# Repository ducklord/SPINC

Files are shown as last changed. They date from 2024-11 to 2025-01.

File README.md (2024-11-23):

# SPINC - DIY Automatic Battery Charger

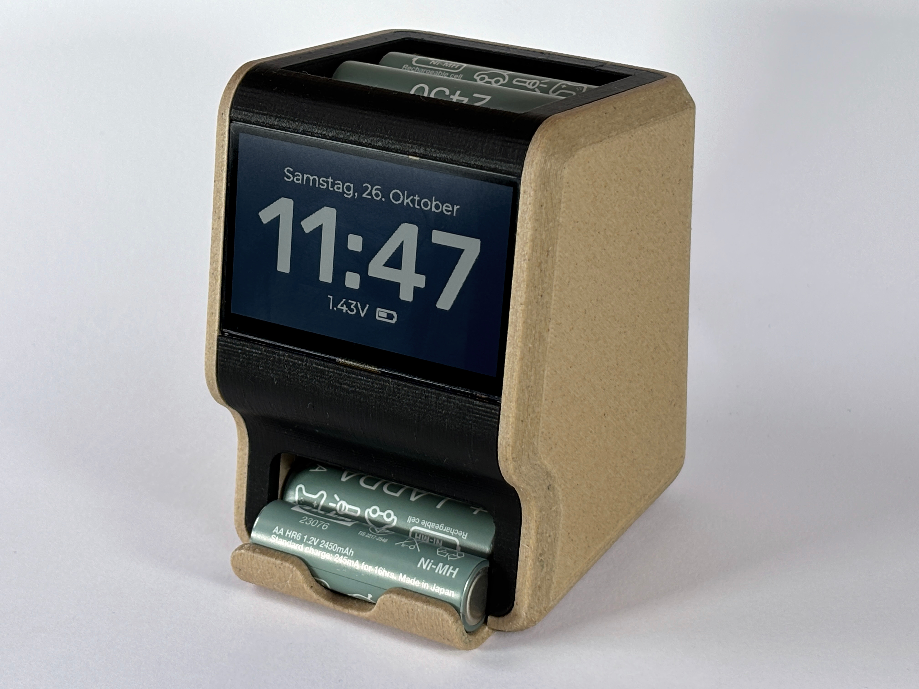
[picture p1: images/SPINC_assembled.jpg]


## Overview

SPINC is an Open-Source NiMH charging station that can automatically load and eject AA battery cells. Simply drop batteries into the top of the device, regardless of their polarity. The internal mechanism picks up one cell at a time and fast-charges them sequentially. Up to 7 fully charged batteries can be conveniently stored inside the device for easy access. In addition, SPINC doubles as a desk clock, displaying the date and time on its high-resolution LCD.

<div align="center">
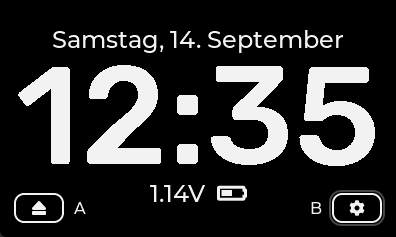
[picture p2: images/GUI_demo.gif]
  
</div>

### Features
* Fast-charges AA NiMH cells at up to 1A
* Automatic cell loading and ejection
* Electronic polarity-correction
* Voltage, temperature and charge time monitoring
* 240x400px monochrome LCD
* Date and time display using LVGL interface
* Compact and fully 3D-printed

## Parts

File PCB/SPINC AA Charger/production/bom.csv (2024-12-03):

Designator | Footprint | Quantity | Value | LCSC Part #
C1, C3 | 0603 | 2 | 4.7uF | C15849
C10, C13, C14, C16, C18, C19, C21, C22, C24, C26, C27, C28 | 0603 | 12 | 100nF
C11, C12 | 0603 | 2 | 15pF | C107037
C15, C17, C2, C20, C4, C6, C8, C9 | 0603 | 8 | 1uF | C15849
C25, C5 | 0603 | 2 | 2.2uF
C29 | 0603 | 1 | 1uF
C30 | 0603 | 1 | 10uF | C15849
C7 | 0603 | 1 | 2.2uF | C15849
D1, D5 | 0603 | 2 | LED | C965807
D2, D4 | D_SMA | 2 | MBRA340
D3 | TSOT-23 | 1 | MMBD4148
F1 | 1206 | 1 | 1A
J1 | USB_C_Receptacle_HRO_TYPE-C-31-M-12 | 1 | USB_C_Receptacle_USB2.0 | C2982555
J2 | PinHeader_1x03_P2.54mm_Vertical | 1 | Conn_01x03_Pin
J3 | 68711014022 | 1 | Conn_01x10_Socket | C2919540
J4, J5 | BatteryHolder_Keystone_590 | 2 | Conn_01x01_Pin | C3029553
L1 | L_Bourns_SRP7050TA_7.3x6.6mm | 1 | SRP7050TA-470M
Q1, Q3 | SOT-23 | 2 | DMG2301L | C102619
Q2 | SO-8_3.9x4.9mm_P1.27mm | 1 | DMHC3025LSD | C156387
Q4 | SOT-23 | 1 | DMG2301L
Q5 | SOT-23 | 1 | SI2305CDS
R10, R14 | 0603 | 2 | 2k2 | C114662
R15, R16, R19, R24, R25, R26, R27, R31, R36, R9 | 0603 | 10 | 10k
R18, R23 | 0603 | 2 | 4k7
R2 | 0603 | 1 | 1k
R20 | 0603 | 1 | 0
R21, R22, R28, R29 | 0603 | 4 | 47k
R3, R4 | 0603 | 2 | 5.1k | C114626
R30 | 0603 | 1 | 100
R32 | 0603 | 1 | 22k
R33 | 0603 | 1 | 100k
R34 | 2512 | 1 | 0R124
R35 | 0603 | 1 | 10
R37 | 0603 | 1 | 330
R5 | 0603 | 1 | 100k | C114626
R6 | 0603 | 1 | 57.6k | C114626
R7, R8 | 0603 | 2 | 27
SW1, SW3 | Panasonic_EVQPUM_EVQPUD | 2 | SW_Push | C388642
SW2 | SW_SPST_EVQP2 | 1 | SW_Push | C2915174
TH1, TH2 | 0603 | 2 | Thermistor_NTC | C13564
U1 | WSON-8-1EP_2x2mm_P0.5mm_EP0.9x1.6mm | 1 | LM27761
U2 | SOT-666 | 1 | USBLC6-2P6 | C2827693
U3 | WSON-8-1EP_6x5mm_P1.27mm_EP3.4x4.3mm | 1 | W25Q64JVZPIQ | C2940197
U4 | SOT-23-5 | 1 | AP2112K-3.3 | C51118
U5 | QFN-56-1EP_7x7mm_P0.4mm_EP3.2x3.2mm | 1 | RP2040 | C2040
U7 | VISHAY_VCNL4040_4X2X1.1 | 1 | VCNL4040M3OE | C142526
U8 | TSSOP-16_4.4x5mm_P0.65mm | 1 | DS2712
Y1 | Crystal_SMD_Abracon_ABM8G-4Pin_3.2x2.5mm | 1 | ABM8-272-T3 | C20625731

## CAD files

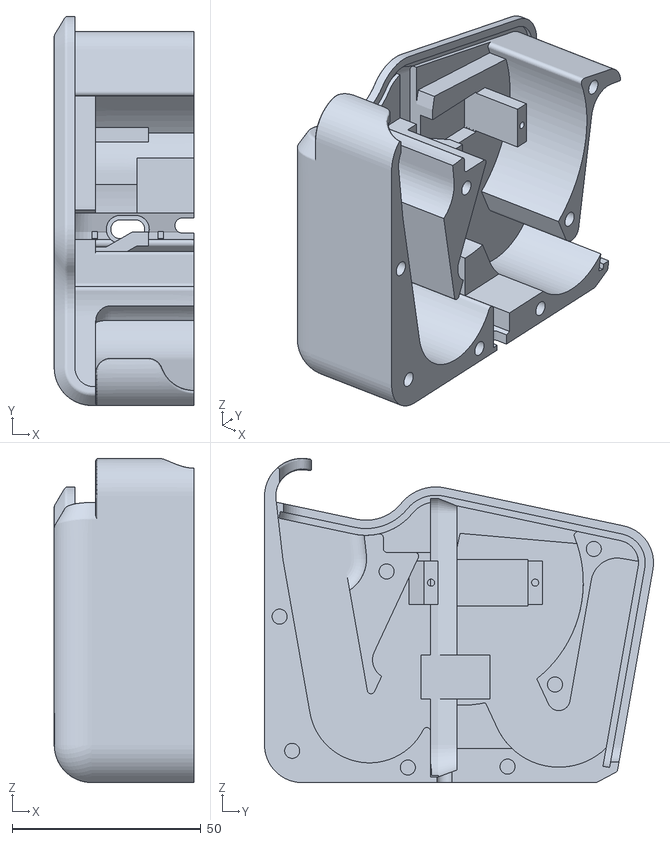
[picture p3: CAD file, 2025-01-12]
CAD/Shell L.stl
37.0 x 103.1 x 85.9

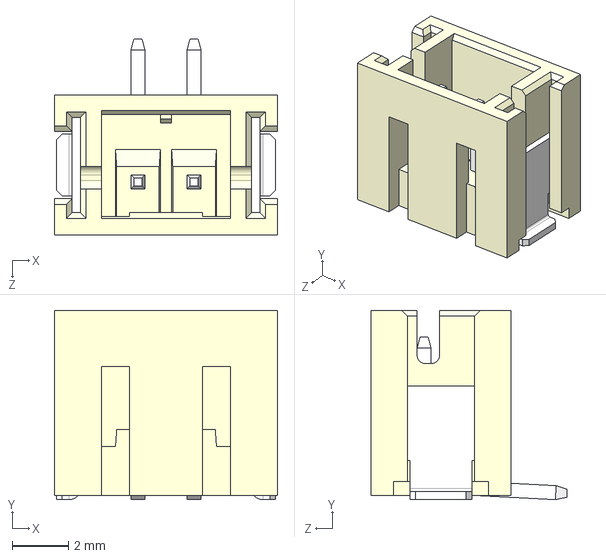
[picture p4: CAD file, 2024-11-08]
PCB/SPINC AA Charger/project_libraries/3D-models/B2B-PH-SM4-TB.STEP
7.95 x 6.75 x 7.00 mm

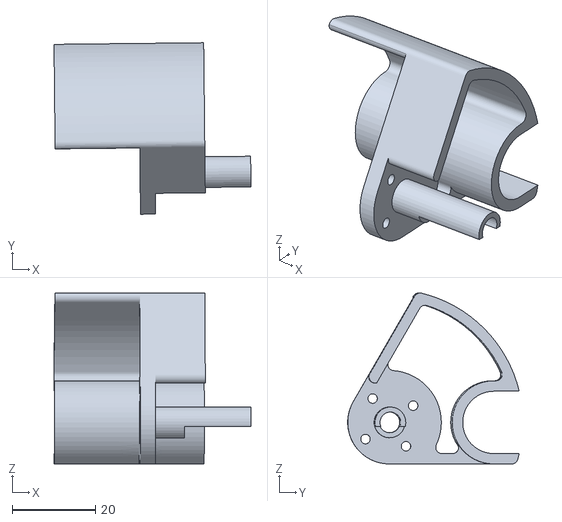
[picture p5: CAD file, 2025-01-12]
CAD/Arm.stl
47.4 x 41.3 x 41.1

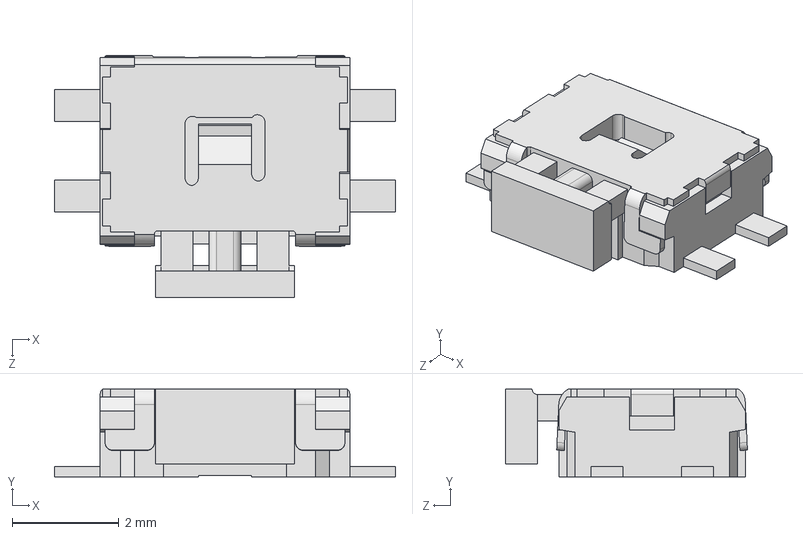
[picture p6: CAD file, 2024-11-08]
PCB/SPINC AA Charger/project_libraries/3D-models/EVQPU-JA-02K.STEP
6.40 x 1.65 x 4.54 mm

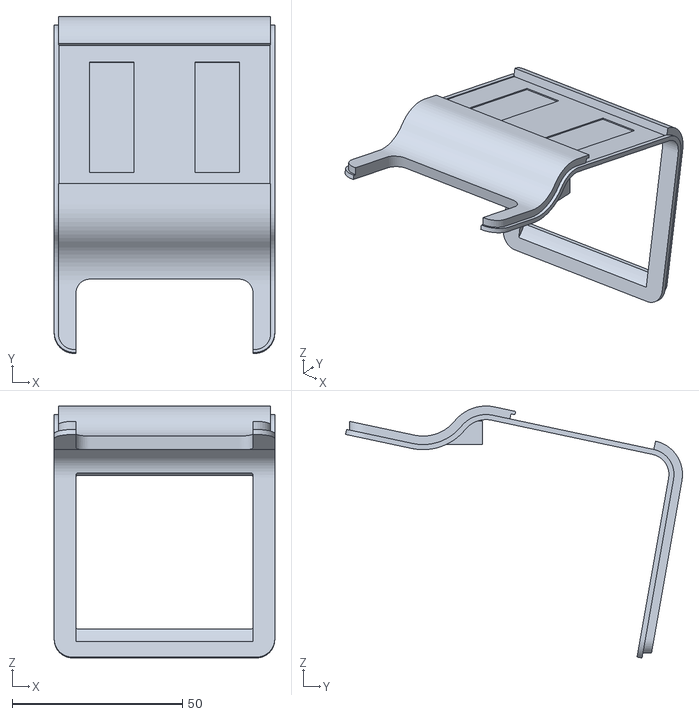
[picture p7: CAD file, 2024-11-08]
CAD/Frontpanel.stl
64.8 x 99.0 x 74.0

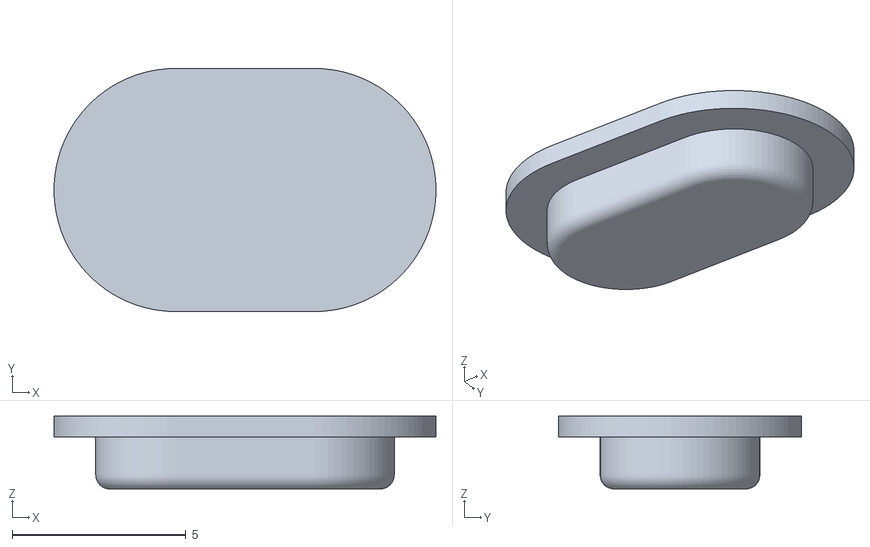
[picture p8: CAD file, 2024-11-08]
CAD/Button.stl
11.0 x 7.00 x 2.10

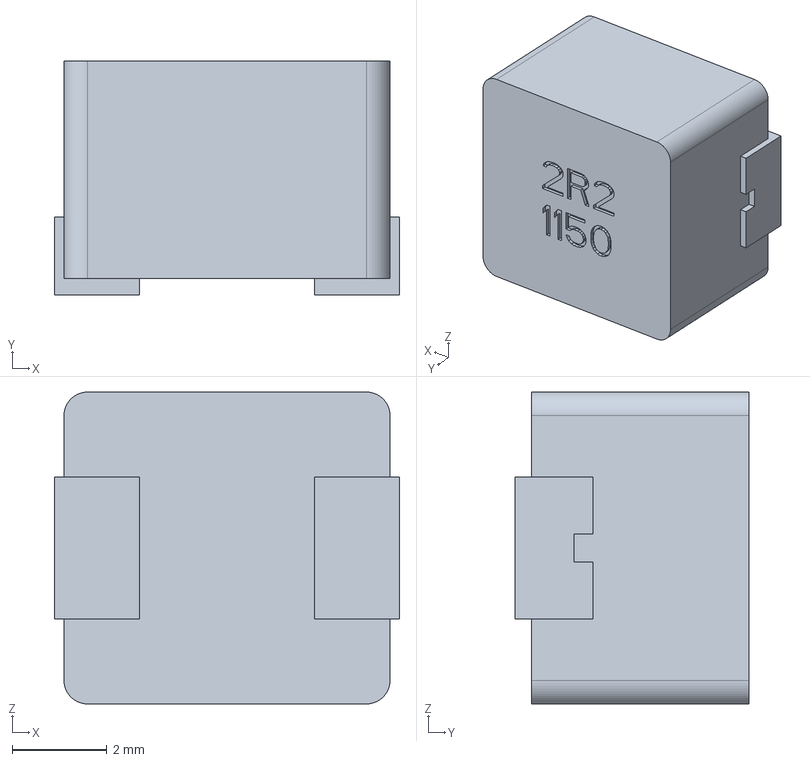
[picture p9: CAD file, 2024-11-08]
PCB/SPINC AA Charger/project_libraries/3D-models/SRP7050TA.stp
7.30 x 4.95 x 6.60 mm

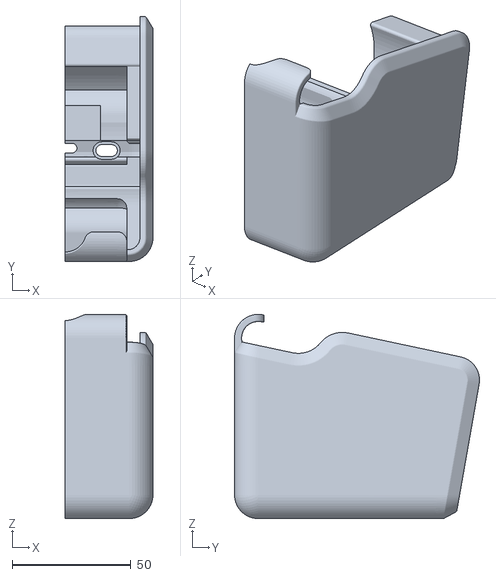
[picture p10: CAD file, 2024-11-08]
CAD/Shell R.stl
37.0 x 103.1 x 85.9

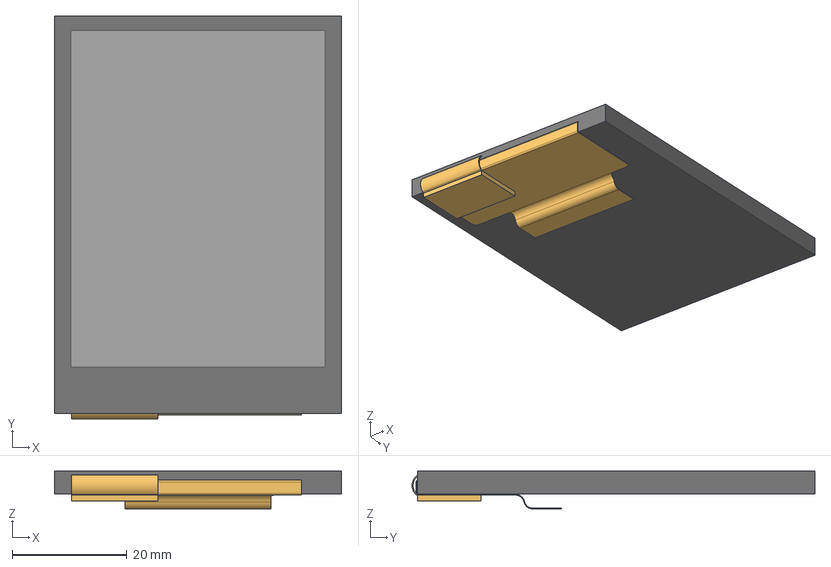
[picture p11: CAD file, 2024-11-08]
PCB/SPINC AA Charger/project_libraries/3D-models/280QV10 v5.step
50.0 x 70.2 x 6.60 mm

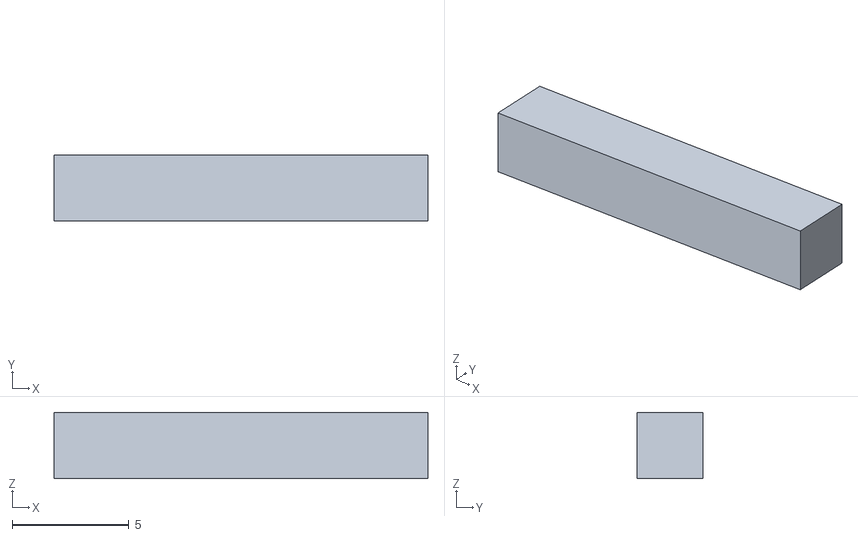
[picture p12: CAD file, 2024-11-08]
CAD/Connector Pin.stl
16.0 x 2.83 x 2.83

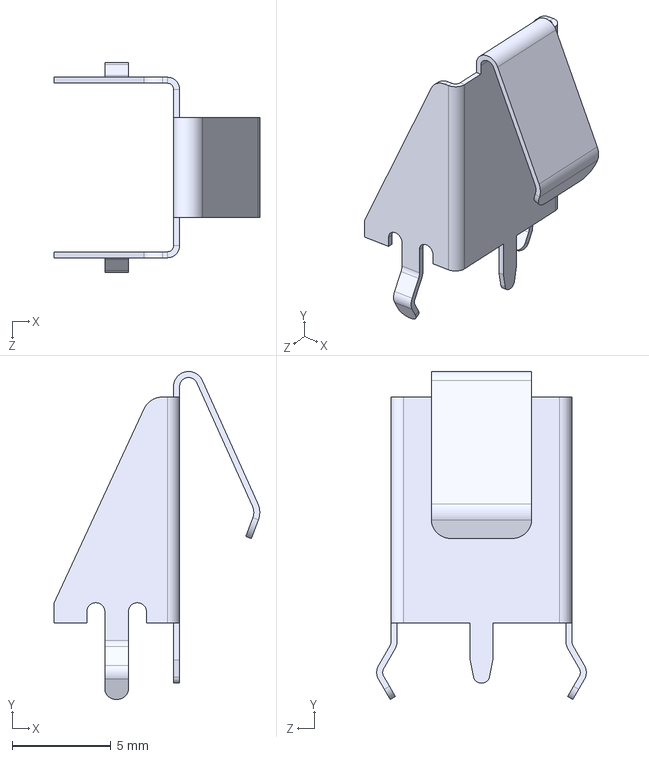
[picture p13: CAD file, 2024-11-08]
PCB/SPINC AA Charger/project_libraries/3D-models/keystone-PN590.STEP
10.4 x 16.6 x 10.6 mm

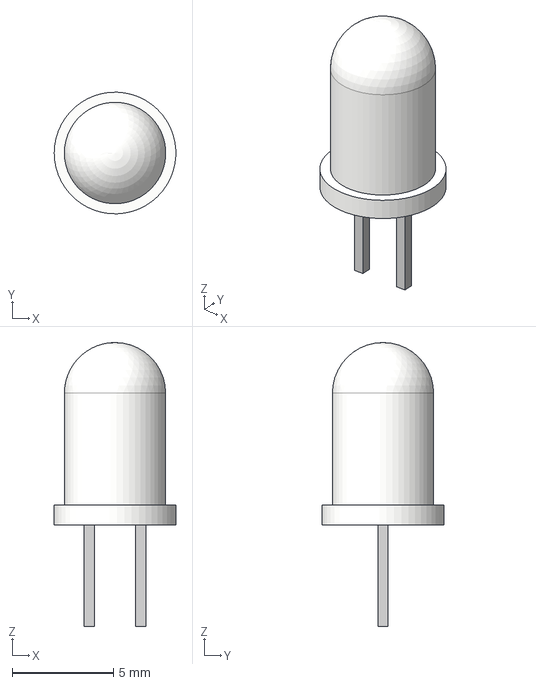
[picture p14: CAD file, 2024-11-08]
PCB/SPINC AA Charger/project_libraries/3D-models/Side Mount LED v1.step
5.99 x 6.00 x 14.0 mm

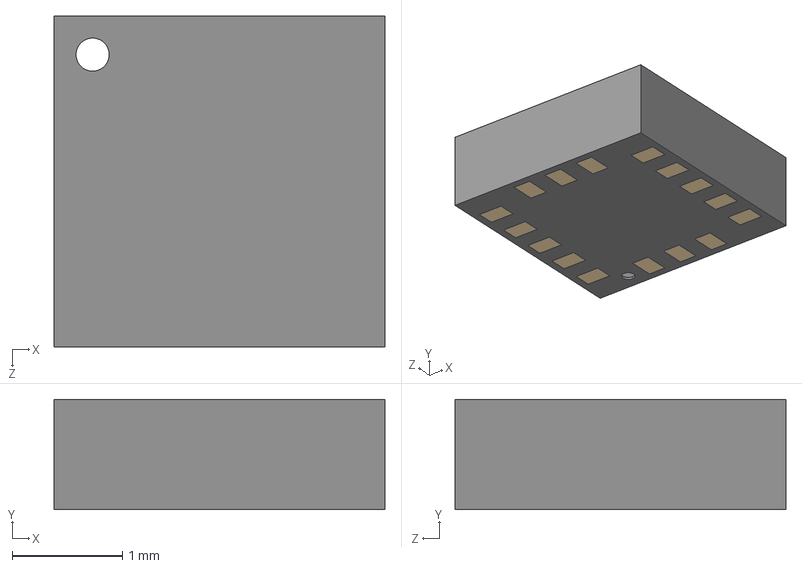
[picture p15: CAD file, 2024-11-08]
PCB/SPINC AA Charger/project_libraries/3D-models/LIS3DHTR.step
3.00 x 1.00 x 3.00 mm

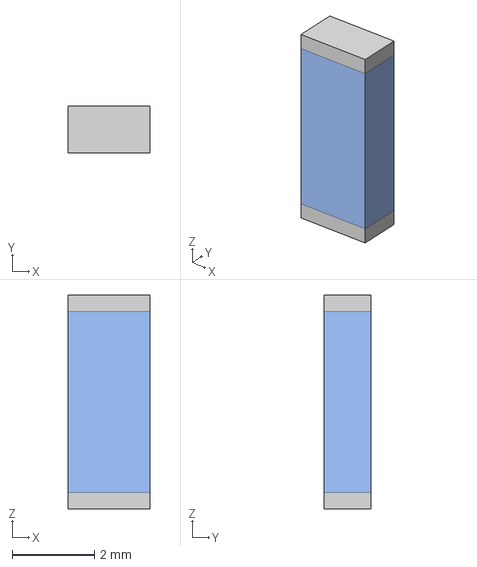
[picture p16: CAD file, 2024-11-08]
PCB/SPINC AA Charger/project_libraries/3D-models/Walsin RFANT5220110A2T v1.step
2.00 x 1.15 x 5.20 mm

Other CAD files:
PCB/SPINC AA Charger/project_libraries/3D-models/82672Heimdall.step
PCB/SPINC AA Charger/project_libraries/3D-models/68711014022 (rev1).stp
PCB/SPINC AA Charger/project_libraries/3D-models/84352VCNL4040.stp
PCB/SPINC AA Charger/project_libraries/3D-models/541325062_colored.step

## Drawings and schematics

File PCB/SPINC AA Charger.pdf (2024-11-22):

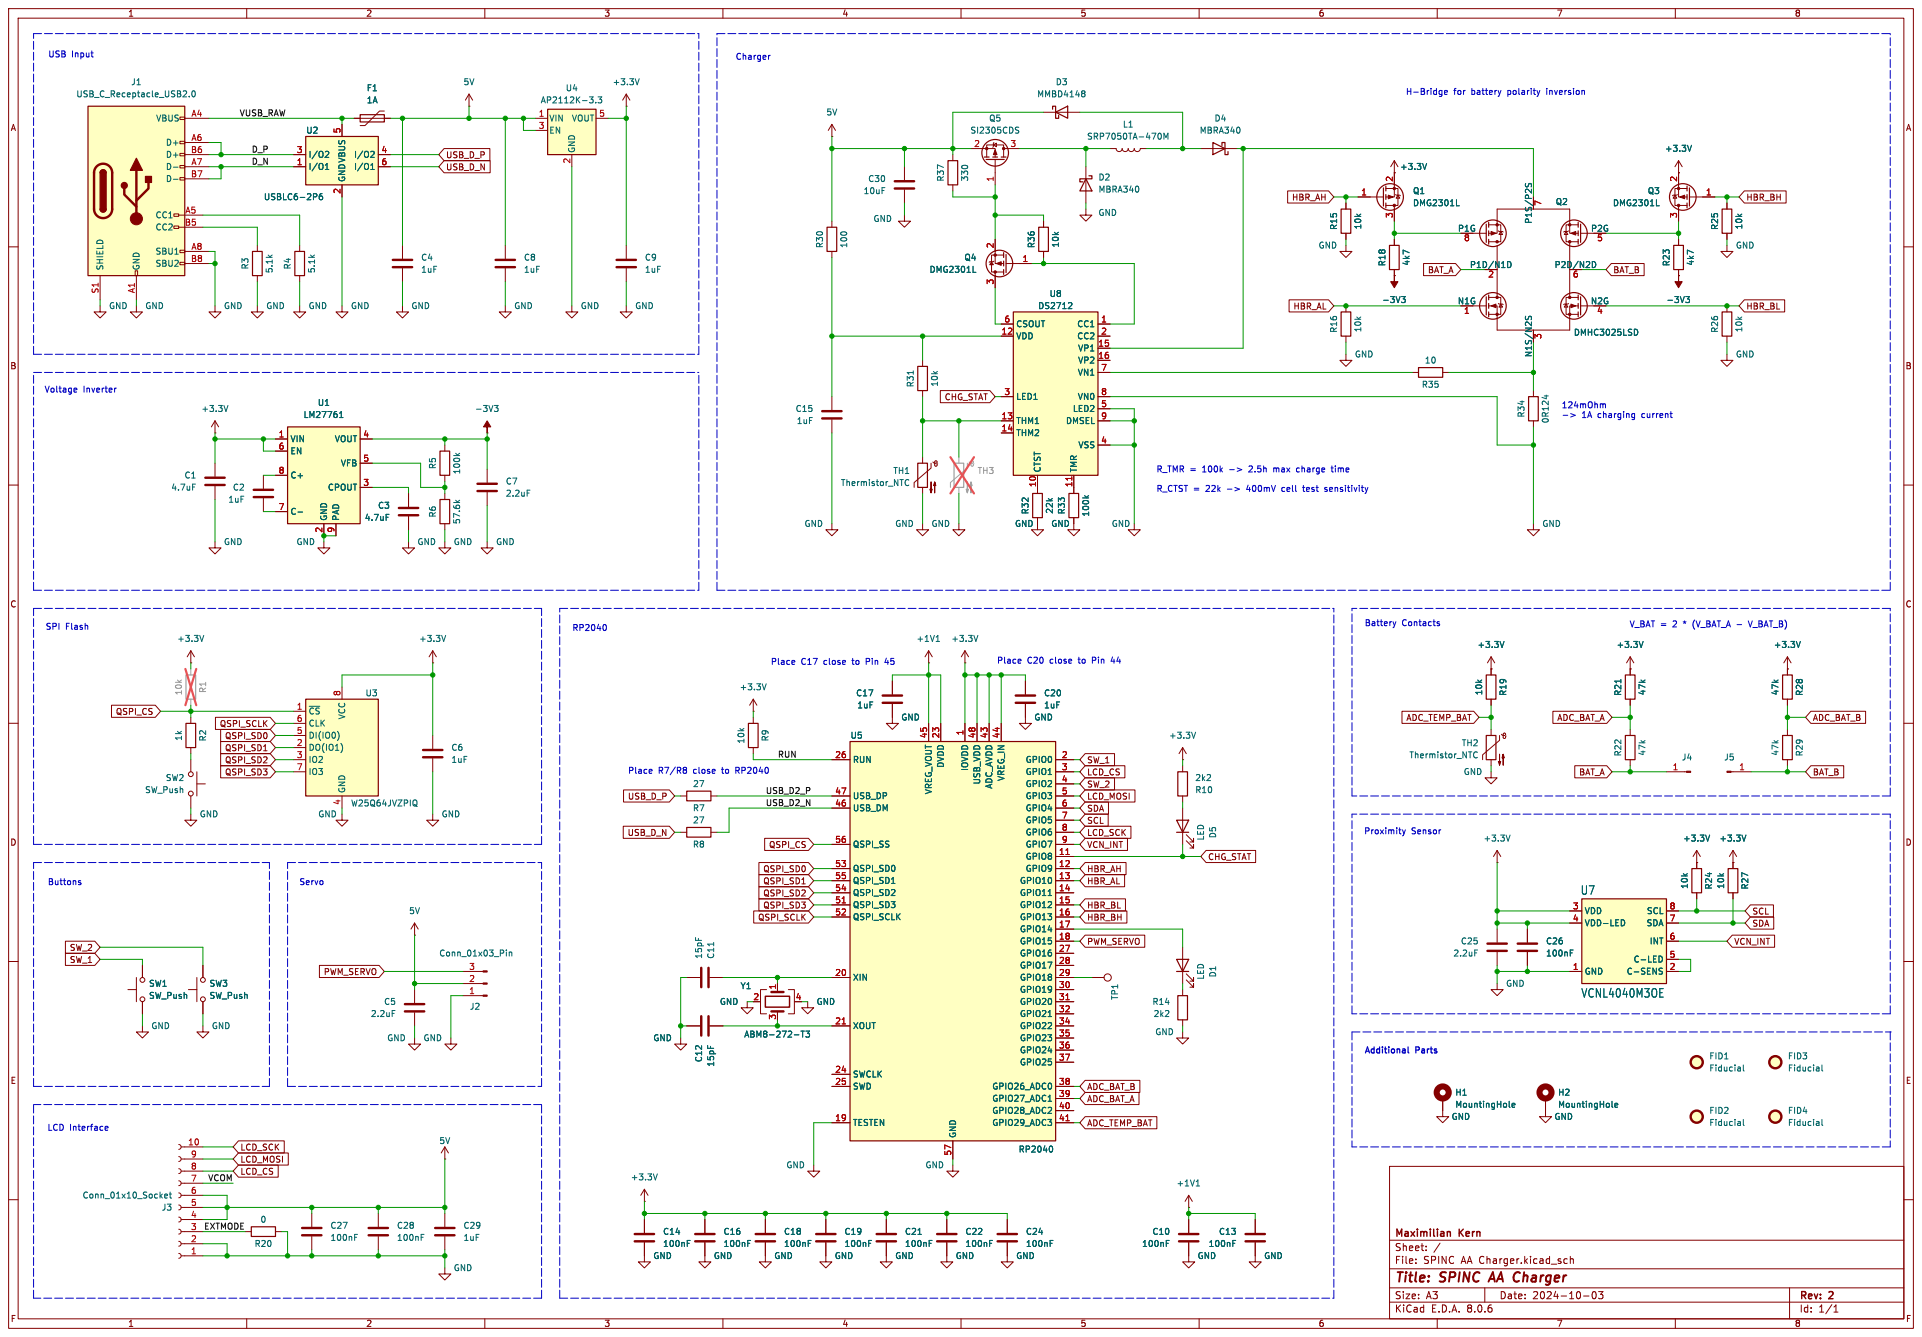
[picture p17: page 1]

2 CPOUT 3 VOUT 4 VFB 5 EN 6 C- 7 C+ 8 PAD

1 GPIO8 11 GPIO9 12 GPIO10 13 GPIO11 14 GPIO12 15 GPIO13 16 GPIO14 17 GPIO15 18 TESTEN 19 GPIO0 2 XIN 20 XOUT 21 DVDD 23 SWCLK 24 SWD 25 RUN 26 GPIO16 27 GPIO17 28 GPIO18 29 GPIO1 3 GPIO19 30 GPIO20 31 GPIO21 32 GPIO22 34 GPIO23 35 GPIO24 36 GPIO25 37 GPIO26_ADC0 38 GPIO27_ADC1 39 GPIO2 4 GPIO28_ADC2 40 GPIO29_ADC3 41 ADC_AVDD 43 VREG_IN 44 VREG_VOUT 45 USB_DM 46 USB_DP 47 USB_VDD 48 GPIO3 5 QSPI_SD3 51 QSPI_SCLK 52 QSPI_SD0 53 QSPI_SD2 54 QSPI_SD1 55 QSPI_SS 56 GND 57 GPIO4 6 GPIO5 7 GPIO6 8 GPIO7 9 U5 RP2040 GND

1 GPIO8 11 GPIO9 12 GPIO10 13 GPIO11 14 GPIO12 15 GPIO13 16 GPIO14 17 GPIO15 18 TESTEN 19 GPIO0 2 XIN 20 XOUT 21 DVDD 23 SWCLK 24 SWD 25 RUN 26 GPIO16 27 GPIO17 28 GPIO18 29 GPIO1 3 GPIO19 30 GPIO20 31 GPIO21 32 GPIO22 34 GPIO23 35 GPIO24 36 GPIO25 37 GPIO26_ADC0 38 GPIO27_ADC1 39 GPIO2 4 GPIO28_ADC2 40 GPIO29_ADC3 41 ADC_AVDD 43 VREG_IN 44 VREG_VOUT 45 USB_DM 46 USB_DP 47 USB_VDD 48 GPIO3 5 QSPI_SD3 51 QSPI_SCLK 52 QSPI_SD0 53 QSPI_SD2 54 QSPI_SD1 55 QSPI_SS 56 GND 57 GPIO4 6 GPIO5 7 GPIO6 8 GPIO7 9 GND

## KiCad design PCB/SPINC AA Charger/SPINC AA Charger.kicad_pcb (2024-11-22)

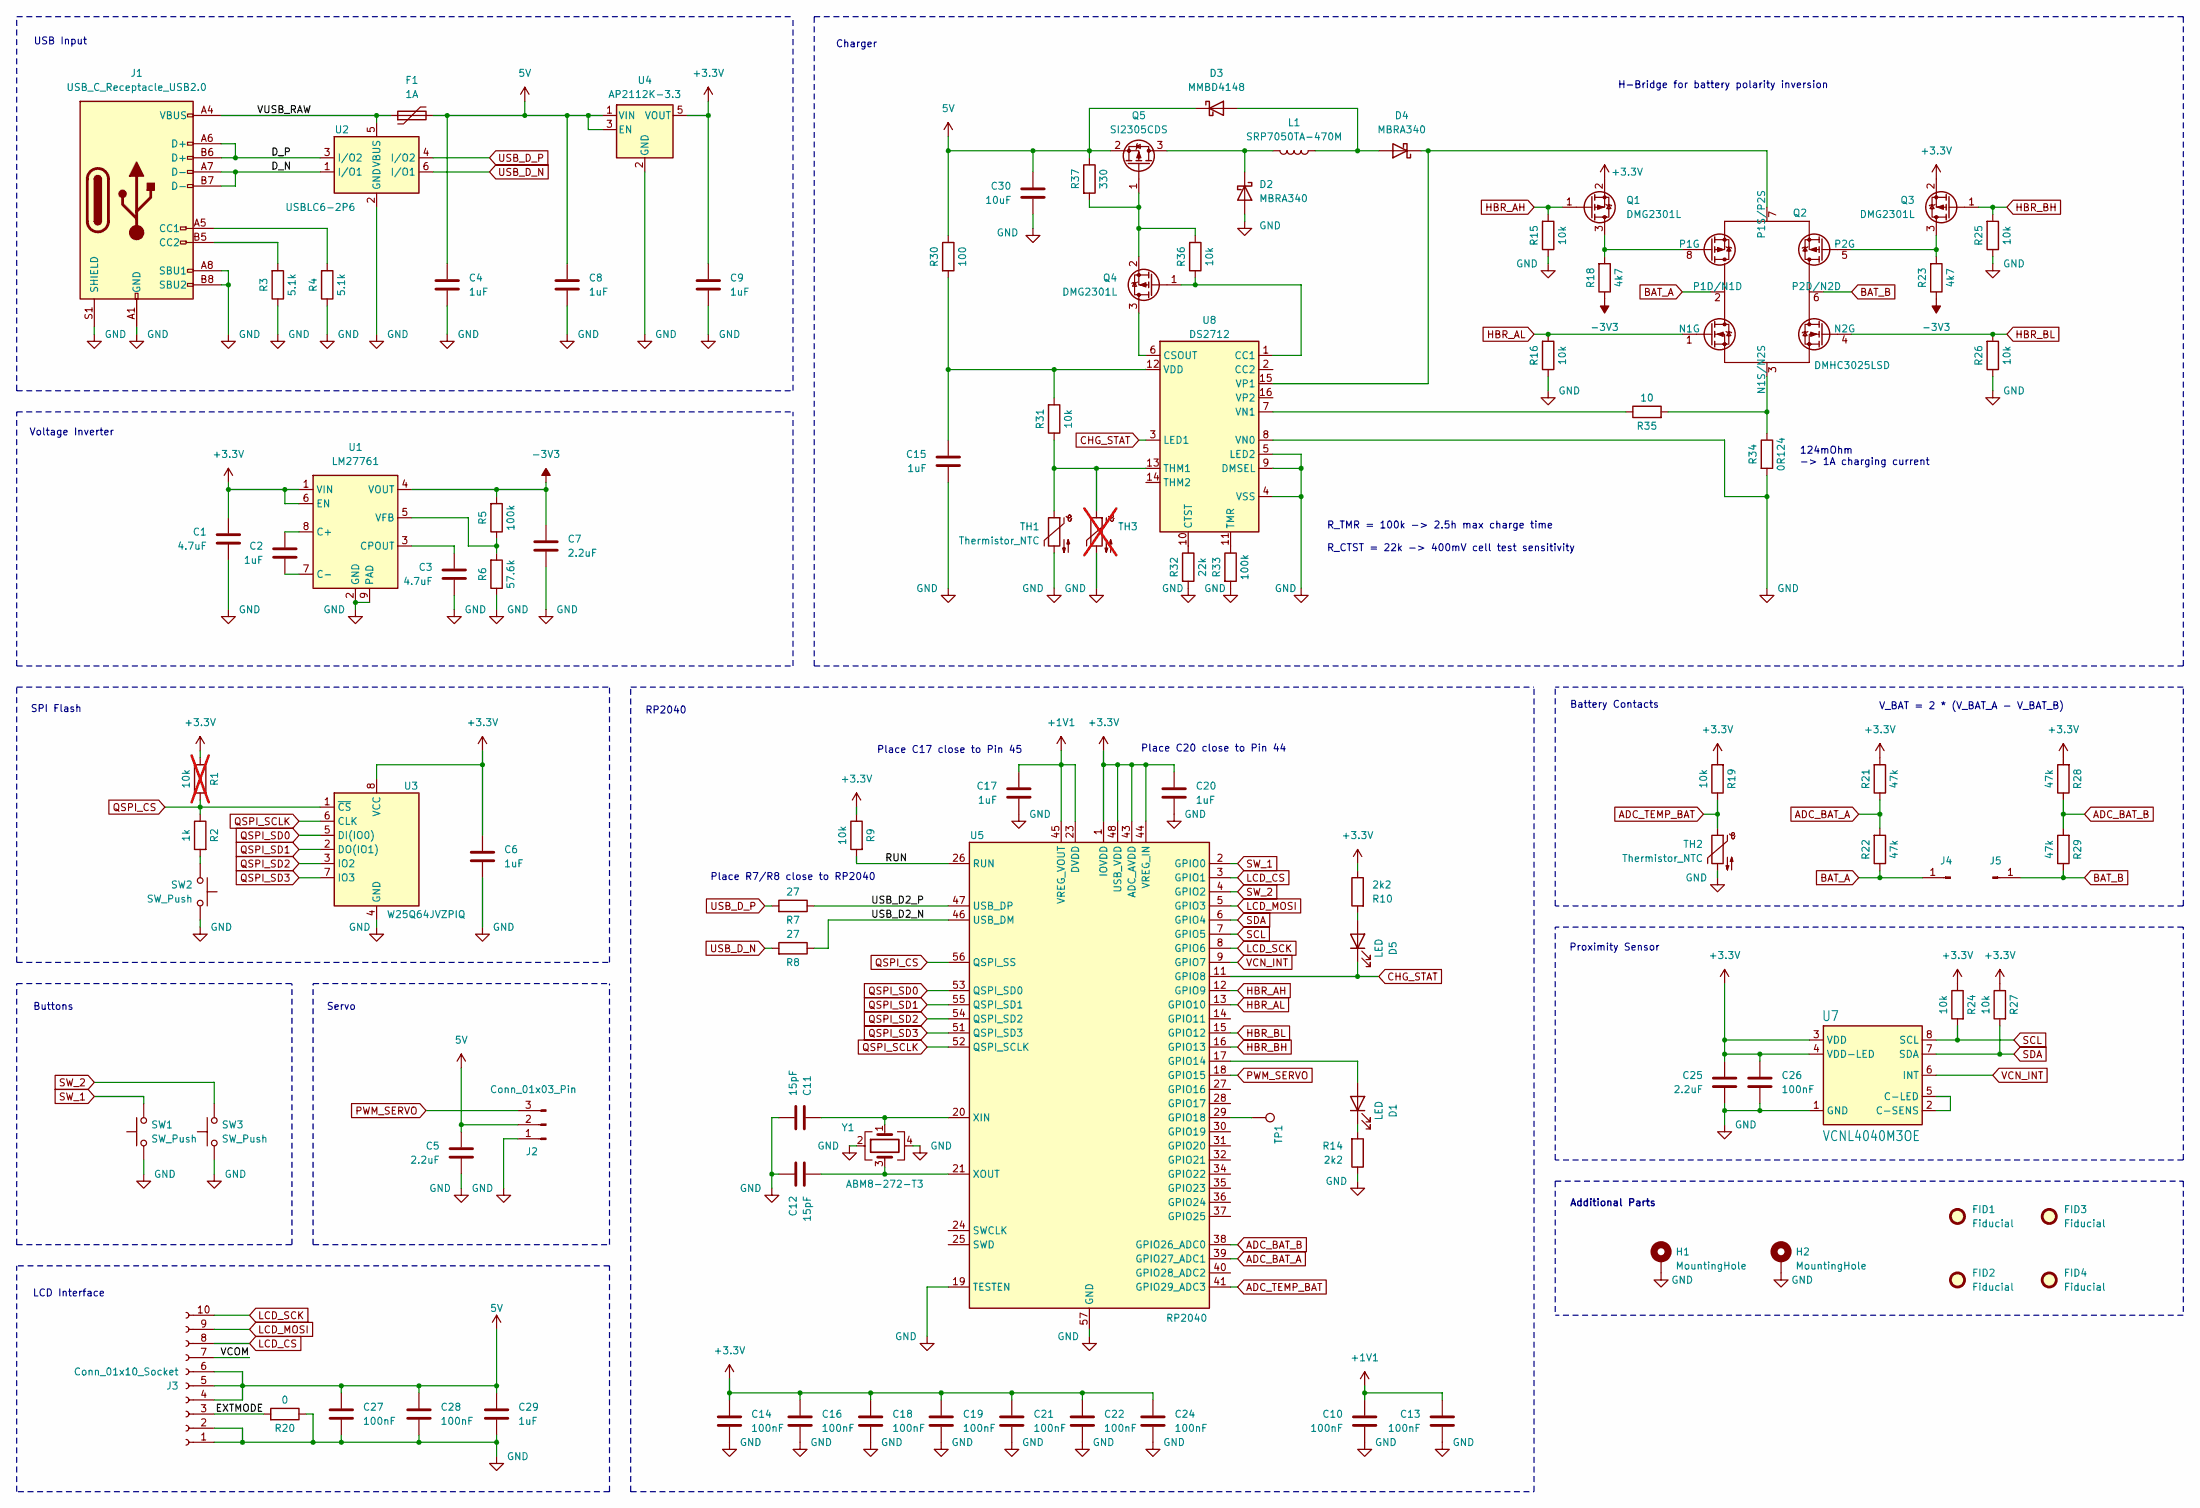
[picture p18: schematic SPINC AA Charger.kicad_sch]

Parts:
C1, C3: 4.7uF; C_0603_1608Metric; LCSC C15849
C2, C4, C6, C8, C9, C15, C17, C20: 1uF; C_0603_1608Metric; LCSC C15849
C5, C25: 2.2uF; C_0603_1608Metric
C7: 2.2uF; C_0603_1608Metric; LCSC C15849
C10, C13, C14, C16, C18, C19, C21, C22, C24, C26, C27, C28: 100nF; C_0603_1608Metric
C11, C12: 15pF; C_0603_1608Metric; LCSC C107037
C29: 1uF; C_0603_1608Metric
C30: 10uF; C_0603_1608Metric; LCSC C15849
D1, D5: LED; LED_0603_1608Metric; LCSC C965807
D2, D4: MBRA340; D_SMA
D3: MMBD4148; TSOT-23
F1: 1A; Fuse_1206_3216Metric_Pad1.42x1.75mm_HandSolder
FID1, FID2, FID3, FID4: Fiducial; Fiducial_1mm_Mask2mm
H1, H2: MountingHole; MountingHole_3.2mm_M3_Pad_Via
J1: USB_C_Receptacle_USB2.0; USB_C_Receptacle_HRO_TYPE-C-31-M-12; LCSC C2982555
J2: Conn_01x03_Pin; PinHeader_1x03_P2.54mm_Vertical
J3: Conn_01x10_Socket; 68711014022; LCSC C2919540
J4, J5: Conn_01x01_Pin; BatteryHolder_Keystone_590; LCSC C3029553
L1: SRP7050TA-470M; L_Bourns_SRP7050TA_7.3x6.6mm
Q1, Q3: DMG2301L; SOT-23; LCSC C102619
Q2: DMHC3025LSD; SO-8_3.9x4.9mm_P1.27mm; LCSC C156387
Q4: DMG2301L; SOT-23
Q5: SI2305CDS; SOT-23
R1: 10k; R_0603_1608Metric; not fitted
R2: 1k; R_0603_1608Metric
R3, R4: 5.1k; R_0603_1608Metric; LCSC C114626
R5: 100k; R_0603_1608Metric; LCSC C114626
R6: 57.6k; R_0603_1608Metric; LCSC C114626
R7, R8: 27; R_0603_1608Metric
R9, R15, R16, R19, R24, R25, R26, R27, R31, R36: 10k; R_0603_1608Metric
R10, R14: 2k2; R_0603_1608Metric; LCSC C114662
R18, R23: 4k7; R_0603_1608Metric
R20: 0; R_0603_1608Metric
R21, R22, R28, R29: 47k; R_0603_1608Metric
R30: 100; R_0603_1608Metric
R32: 22k; R_0603_1608Metric
R33: 100k; R_0603_1608Metric
R34: 0R124; R_2512_6332Metric
R35: 10; R_0603_1608Metric
R37: 330; R_0603_1608Metric
SW1, SW3: SW_Push; Panasonic_EVQPUM_EVQPUD; LCSC C388642
SW2: SW_Push; SW_SPST_EVQP2; LCSC C2915174
TH1, TH2: Thermistor_NTC; R_0603_1608Metric; LCSC C13564
TH3: Thermistor_NTC; R_LDR_4.9x4.2mm_P2.54mm_Vertical; not fitted
TP1: TestPoint; TestPoint_Pad_D1.5mm
U1: LM27761; WSON-8-1EP_2x2mm_P0.5mm_EP0.9x1.6mm
U2: USBLC6-2P6; SOT-666; LCSC C2827693
U3: W25Q64JVZPIQ; WSON-8-1EP_6x5mm_P1.27mm_EP3.4x4.3mm; LCSC C2940197
U4: AP2112K-3.3; SOT-23-5; LCSC C51118
U5: RP2040; QFN-56-1EP_7x7mm_P0.4mm_EP3.2x3.2mm; LCSC C2040
U7: VCNL4040M3OE; VISHAY_VCNL4040_4X2X1.1; LCSC C142526
U8: DS2712; TSSOP-16_4.4x5mm_P0.65mm
Y1: ABM8-272-T3; Crystal_SMD_Abracon_ABM8G-4Pin_3.2x2.5mm; LCSC C20625731

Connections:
5V: C4.1, C5.1, C8.1, C27.1, C28.1, C29.1, C30.1, D3.3 (K), F1.2, J2.2, J3.4, J3.5, J3.6, Q5.2 (S), R30.1, R37.1, U4.1 (VIN), U4.3 (EN)
+1V1: C10.1, C13.1, C17.1, U5.23 (DVDD), U5.45 (VREG_VOUT), U5.50 (DVDD)
+3.3V: C1.1, C6.1, C9.1, C14.1, C16.1, C18.1, C19.1, C20.1, C21.1, C22.1, C24.1, C25.1, C26.1, Q1.2 (S), Q3.2 (S), R1.1, R9.1, R10.1, R19.2, R21.2, R24.1, R27.1, R28.2, U1.1 (VIN), U1.6 (EN), U3.8 (VCC), U4.5 (VOUT), U5.1 (IOVDD), U5.10 (IOVDD), U5.22 (IOVDD), U5.33 (IOVDD), U5.42 (IOVDD), U5.43 (ADC_AVDD), U5.44 (VREG_IN), U5.48 (USB_VDD), U5.49 (IOVDD), U7.3 (VDD), U7.4 (VDD-LED)
-3V3: C7.1, R5.2, R18.1, R23.1, U1.4 (VOUT)
/D_N: J1.A7 (D-), J1.B7 (D-), U2.1 (I/O1)
/D_P: J1.A6 (D+), J1.B6 (D+), U2.3 (I/O2)
/EXTMODE: J3.3, R20.2
/RUN: R9.2, U5.26 (RUN)
/USB_D2_N: R8.1, U5.46 (USB_DM)
/USB_D2_P: R7.1, U5.47 (USB_DP)
/VCOM: J3.7
/VUSB_RAW: F1.1, J1.A4 (VBUS), J1.A9 (VBUS), J1.B4 (VBUS), J1.B9 (VBUS), U2.5 (VBUS)
ADC_BAT_A: R21.1, R22.2, U5.39 (GPIO27_ADC1)
ADC_BAT_B: R28.1, R29.2, U5.38 (GPIO26_ADC0)
ADC_TEMP_BAT: R19.1, TH2.1, U5.41 (GPIO29_ADC3)
BAT_A: J4.1, Q2.2 (P1D/N1D), R22.1
BAT_B: J5.1, Q2.6 (P2D/N2D), R29.1
CHG_STAT: D5.1 (K), U5.11 (GPIO8), U8.3 (LED1)
GND: C1.2, C3.2, C4.2, C5.2, C6.2, C7.2, C8.2, C9.2, C10.2, C11.2, C12.1, C13.2, C14.2, C15.2, C16.2, C17.2, C18.2, C19.2, C20.2, C21.2, C22.2, C24.2, C25.2, C26.2, C27.2, C28.2, C29.2, C30.2, D2.2 (A), H1.1, H2.1, J1.A1 (GND), J1.A8 (SBU1), J1.A12 (GND), J1.B1 (GND), J1.B8 (SBU2), J1.B12 (GND), J1.S1 (SHIELD), J2.1, J3.1, J3.2, R3.1, R4.1, R6.1, R14.1, R15.1, R16.1, R20.1, R25.1, R26.1, R32.2, R33.2, R34.2, SW1.1, SW2.1, SW3.1, TH1.2, TH2.2, TH3.2, U1.2 (GND), U1.9 (PAD), U2.2 (GND), U3.4 (GND), U4.2 (GND), U5.19 (TESTEN), U5.57 (GND), U7.1 (GND), U8.4 (VSS), U8.5 (LED2), U8.8 (VN0), U8.9 (DMSEL), Y1.2, Y1.4
HBR_AH: Q1.1 (G), R15.2, U5.12 (GPIO9)
HBR_AL: Q2.1 (N1G), R16.2, U5.13 (GPIO10)
HBR_BH: Q3.1 (G), R25.2, U5.16 (GPIO13)
HBR_BL: Q2.4 (N2G), R26.2, U5.15 (GPIO12)
LCD_CS: J3.8, U5.3 (GPIO1)
LCD_MOSI: J3.9, U5.5 (GPIO3)
LCD_SCK: J3.10, U5.8 (GPIO6)
unnamed: D1.2 (A), U5.17 (GPIO14)
unnamed: D1.1 (K), R14.2
unnamed: D2.1 (K), L1.2, Q5.3 (D)
unnamed: D3.1 (A), D4.2 (A), L1.1
unnamed: D4.1 (K), Q2.7 (P1S/P2S), U8.15 (VP1)
unnamed: D5.2 (A), R10.2
unnamed: J1.A5 (CC1), R4.2
unnamed: J1.B5 (CC2), R3.2
unnamed: Q1.3 (D), Q2.8 (P1G), R18.2
unnamed: Q2.3 (N1S/N2S), R34.1, R35.2
unnamed: Q2.5 (P2G), Q3.3 (D), R23.2
unnamed: Q4.3 (D), U8.6 (CSOUT)
unnamed: Q4.1 (G), R36.1, U8.1 (CC1)
unnamed: Q4.2 (S), Q5.1 (G), R36.2, R37.2
unnamed: R2.2, SW2.2
unnamed: C2.1, U1.8 (C+)
unnamed: C2.2, U1.7 (C-)
unnamed: C3.1, U1.3 (CPOUT)
unnamed: R5.1, R6.2, U1.5 (VFB)
unnamed: TP1.1, U5.29 (GPIO18)
unnamed: C11.1, U5.20 (XIN), Y1.1
unnamed: C12.2, U5.21 (XOUT), Y1.3
unnamed: U7.2 (C-SENS), U7.5 (C-LED)
unnamed: R32.1, U8.10 (CTST)
unnamed: R31.1, TH1.1, TH3.1, U8.13 (THM1)
unnamed: R33.1, U8.11 (TMR)
unnamed: C15.1, R30.2, R31.2, U8.12 (VDD)
unnamed: R35.1, U8.7 (VN1)
PWM_SERVO: J2.3, U5.18 (GPIO15)
QSPI_CS: R1.2, R2.1, U3.1 (~CS), U5.56 (QSPI_SS)
QSPI_SCLK: U3.6 (CLK), U5.52 (QSPI_SCLK)
QSPI_SD0: U3.5 (DI(IO0)), U5.53 (QSPI_SD0)
QSPI_SD1: U3.2 (DO(IO1)), U5.55 (QSPI_SD1)
QSPI_SD2: U3.3 (IO2), U5.54 (QSPI_SD2)
QSPI_SD3: U3.7 (IO3), U5.51 (QSPI_SD3)
SCL: R24.2, U5.7 (GPIO5), U7.8 (SCL)
SDA: R27.2, U5.6 (GPIO4), U7.7 (SDA)
SW_1: SW1.2, U5.2 (GPIO0)
SW_2: SW3.2, U5.4 (GPIO2)
USB_D_N: R8.2, U2.6 (I/O1)
USB_D_P: R7.2, U2.4 (I/O2)
VCN_INT: U5.9 (GPIO7), U7.6 (INT)

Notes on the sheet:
RP2040
Place C17 close to Pin 45
Voltage Inverter
Buttons
Charger
H-Bridge for battery polarity inversion
Place R7/R8 close to RP2040
SPI Flash
Battery Contacts
Additional Parts
Place C20 close to Pin 44
Servo
V_BAT = 2 * (V_BAT_A - V_BAT_B)
LCD Interface
USB Input
Proximity Sensor
124mOhm -> 1A charging current
R_TMR = 100k -> 2.5h max charge time R_CTST = 22k -> 400mV cell test sensitivity

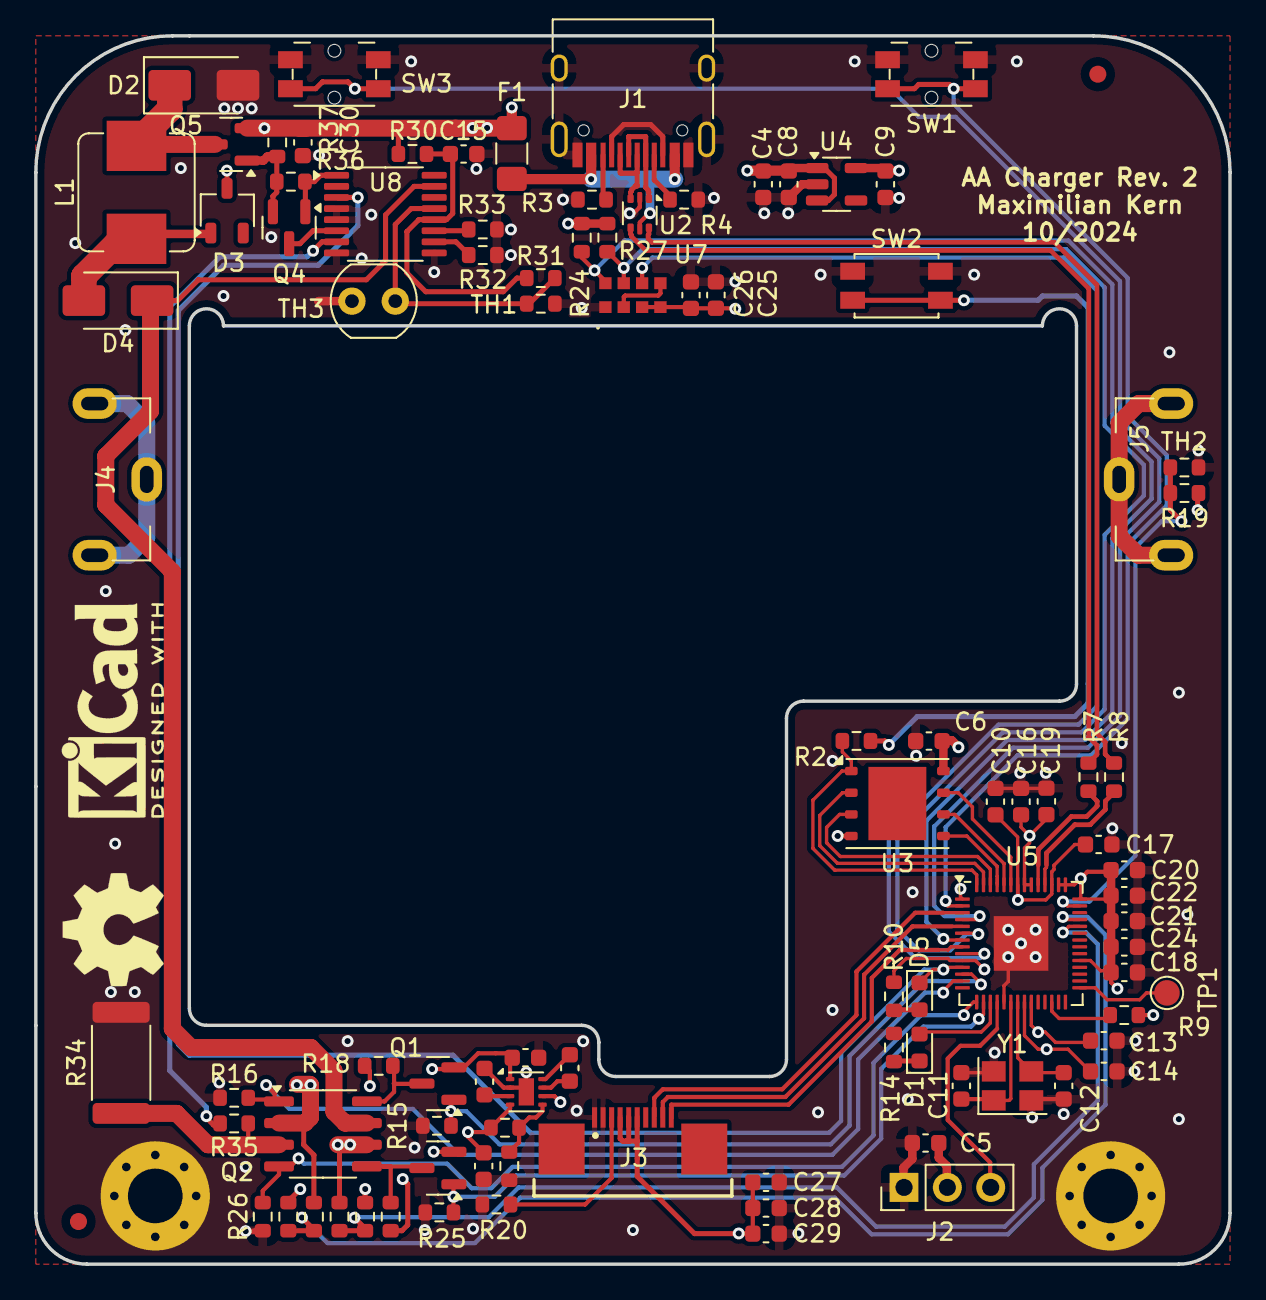
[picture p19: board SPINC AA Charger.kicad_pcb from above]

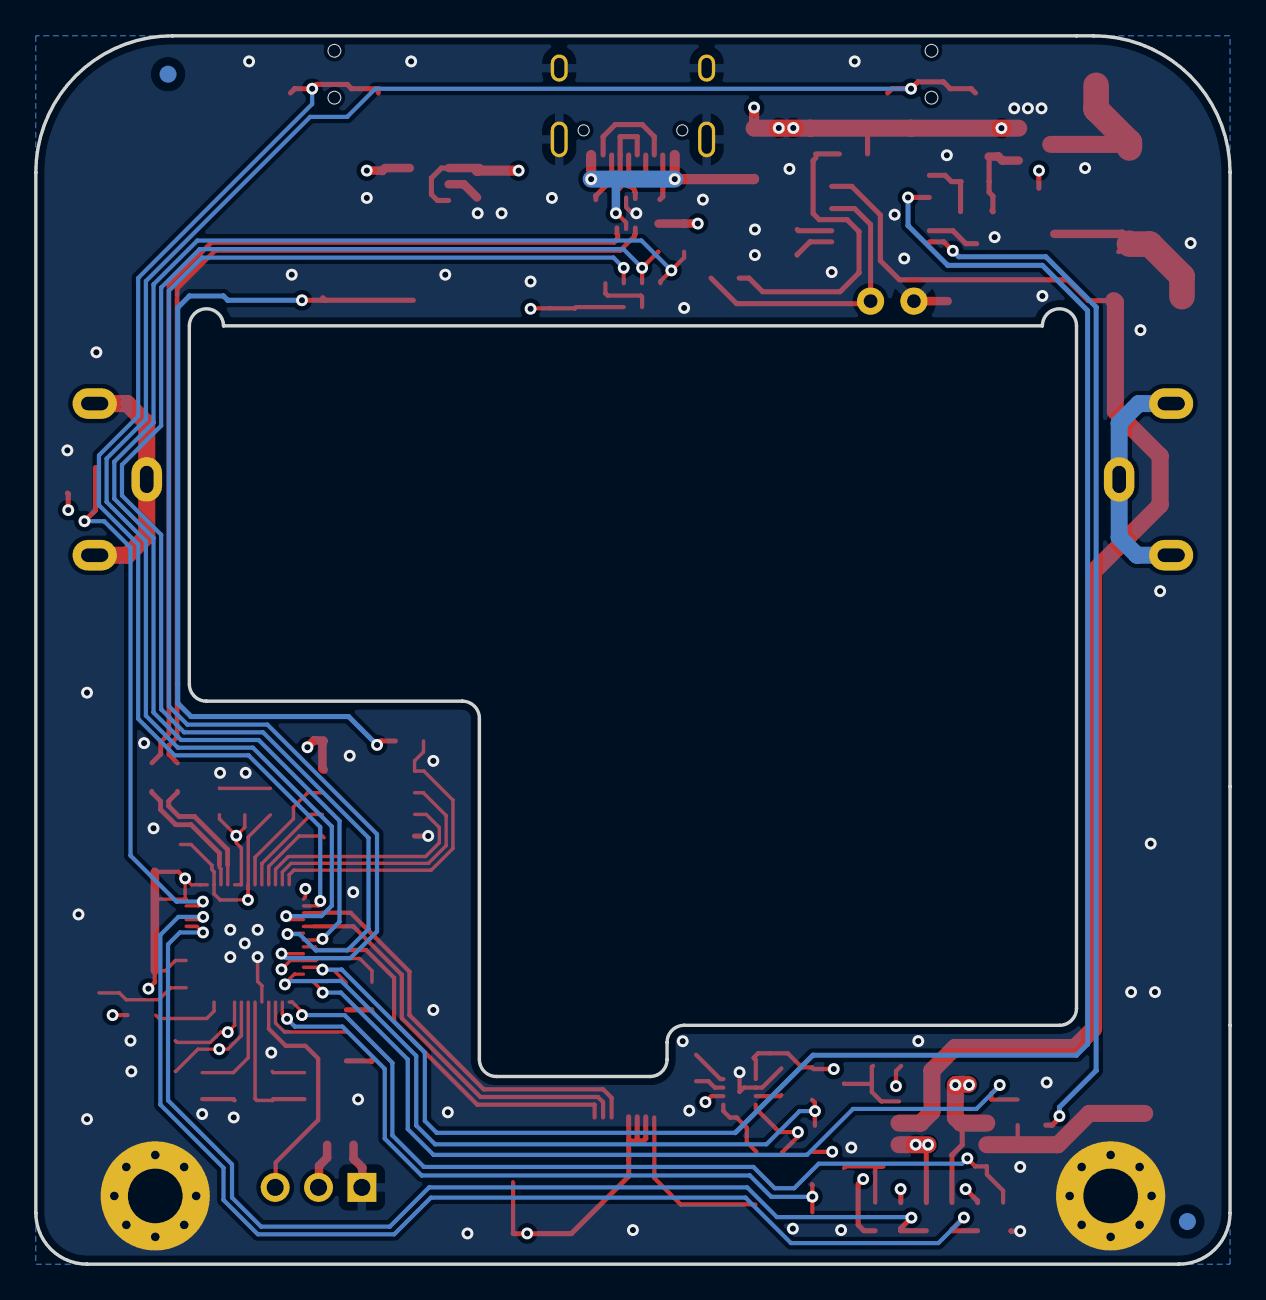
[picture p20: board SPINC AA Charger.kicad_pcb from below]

Board: 4 copper layers, 70.0 x 72.0 mm, 99 parts (2 on the bottom side), 67 nets.

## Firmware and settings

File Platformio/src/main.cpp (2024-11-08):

// SPINC AA Charger Firmware
// 2024 Maximilian Kern

#include <Arduino.h>
#include <Adafruit_VCNL4040.h>
#include <Servo.h>
#include <Adafruit_GFX.h>
#include <Adafruit_SharpMem.h>
#include <lvgl.h>
#include <hardware/rtc.h>

//#define DEBUGDISPLAY

// Pin assignment -----------------------------------------------------------------------------------------------------------------------

#define SW_A 2 // SW_2
#define SW_B 0 // SW_1
#define USER_LED 14 // 25 for Pico

#define LCD_CS 1
#define LCD_MOSI 3
#define LCD_SCK 6

#define SDA 4
#define SCL 5
#define VCN_INT 7

#define CHG_STAT 8
#define CHG_TMR 11

#define PWM_SERVO 15

#define HBR_AH 9
#define HBR_AL 10
#define HBR_BL 12
#define HBR_BH 13

#define ADC_BAT_A A0
#define ADC_BAT_B A1
#define ADC_TEMP_BAT A3

// H-bridge declarations
enum HBR_STATE {OFF, A_POS, B_POS};
int hbrdge_currentState = OFF;

// Proximity Sensor declaration
Adafruit_VCNL4040 vcnl4040 = Adafruit_VCNL4040();
const int proxThreshold = 75; // detectipon threshold for detecting battery in input chute

// LCD declarations
Adafruit_SharpMem display(LCD_SCK, LCD_MOSI, LCD_CS, 400, 240, 8000000);
#define screenWidth 400
#define screenHeight 240
#define BLACK 0
#define WHITE 1

// LVGL declarations
static lv_disp_draw_buf_t draw_buf;
static lv_color_t bufA[ screenWidth * screenHeight / 4 ];
static lv_color_t bufB[ screenWidth * screenHeight / 4 ];
lv_obj_t* objBattPercentage;
lv_obj_t* objBattIcon;
lv_obj_t* panel;
lv_obj_t* ChecksTable;
lv_color_t color_primary = lv_color_hex(0x303030); // gray
lv_obj_t * timeLabel;
lv_obj_t * dateLabel;
lv_obj_t * infoLabel;
extern const lv_font_t rubik_140;
lv_obj_t* tabview;
lv_obj_t* dayButton;
lv_obj_t* monthButton;
lv_obj_t* yearButton;
lv_obj_t* weekdayButton;
lv_obj_t* minuteButton;
lv_obj_t* hourButton;
lv_obj_t* dayButtonL;
lv_obj_t* monthButtonL;
lv_obj_t* yearButtonL;
lv_obj_t* weekdayButtonL;
lv_obj_t* minuteButtonL;
lv_obj_t* hourButtonL;
lv_timer_t * returnTimer = NULL;
lv_timer_t * hintTimer = NULL;
bool buttonHintsVisible = true;
lv_obj_t* ejectButton;
lv_obj_t* ejectHint;
lv_obj_t* settingsButton;
lv_obj_t* settingsHint;

Servo servo;
const int LowerServoLimit = 1176; // Servo position for output chute
const int ServoContactPos = 1400; // Servo position for charging
const int UpperServoLimit = 1677; // Servo position for input chute
int currentServoPos = LowerServoLimit;

datetime_t t = {
.year = 2024,
.month = 10,
.day = 26,
.dotw = 6, // 0 is Sunday, so 5 is Friday
.hour = 11,
.min = 42,
.sec = 00
};
datetime_t tOld;
const char* weekdays_GERMAN[7] = {"Sonntag", "Montag", "Dienstag", "Mittwoch", "Donnerstag", "Freitag", "Samstag"};
const char* months_GERMAN[13] = {"", "Januar", "Februar", "März", "April", "Mai", "Juni", "Juli", "August", "September", "Oktober", "November", "Dezember"};

// State machine declarations
enum FSM_STATE {WAKEUP, IDLE, FEED, CONTACT, CHARGE, ENDCHARGE};
int fsm_currentState = IDLE;

// Display flushing
void my_disp_flush( lv_disp_drv_t *disp, const lv_area_t *area, lv_color_t *color_p ){
  uint32_t w = ( area->x2 - area->x1 + 1 );
  uint32_t h = ( area->y2 - area->y1 + 1 );

  int32_t x, y;
    //Lots of room for optimization here
    for(y = area->y1; y <= area->y2; y++) {
        for(x = area->x1; x <= area->x2; x++) {
            display.drawPixel(x, y, lv_color_to16(*color_p));
            color_p++;
        }
    }
  display.refresh();
  lv_disp_flush_ready(disp);
}

// Timer for returning from settings menu to clock screen
static void returnTimer_callback(lv_timer_t * timer)
{
  lv_tabview_set_act(tabview, 0, LV_ANIM_OFF);
}

// Timer for showing the button hints
static void hintTimer_callback(lv_timer_t * timer)
{
  buttonHintsVisible = false;
  lv_obj_add_flag(ejectButton, LV_OBJ_FLAG_HIDDEN);
  lv_obj_add_flag(ejectHint, LV_OBJ_FLAG_HIDDEN);
  lv_obj_add_flag(settingsButton, LV_OBJ_FLAG_HIDDEN);
  lv_obj_add_flag(settingsHint, LV_OBJ_FLAG_HIDDEN);
}

// Input driver - buttons A and A are assigned to NEXT and ENTER
static void keypad_read(lv_indev_drv_t * indev_drv, lv_indev_data_t * data)
{
  static uint32_t last_key = 0;    

  /*Get the pressed key*/
  uint32_t key = 0;
  if(lv_tabview_get_tab_act(tabview) > 0){ // ignore buttons for tab1
    if(!digitalRead(SW_A) || !digitalRead(SW_B)) lv_timer_reset(returnTimer);
    if(!digitalRead(SW_A)) key = LV_KEY_NEXT;
    else if(!digitalRead(SW_B)) key = LV_KEY_ENTER;

  }
  else{
    if(buttonHintsVisible == true){
      if(!digitalRead(SW_A)) fsm_currentState = ENDCHARGE;
      else if(!digitalRead(SW_B)){ // Enter Settings
        lv_tabview_set_act(tabview, 1, LV_ANIM_OFF);
        lv_group_focus_obj(dayButton);
        // Update button labels with initial RTC date and time
        lv_label_set_text_fmt(dayButtonL, "%02d.", t.day);
        lv_label_set_text_fmt(monthButtonL, "%02d.", t.month);
        lv_label_set_text_fmt(yearButtonL, "%04d", t.year);
        lv_label_set_text_fmt(hourButtonL, "%02d:", t.hour);
        lv_label_set_text_fmt(minuteButtonL, "%02d", t.min);
        // start timer to automatically return to tab1
        lv_timer_ready(returnTimer);
        lv_timer_reset(returnTimer);
      }
    }
    else{ // in tab1
      if(!digitalRead(SW_A) || !digitalRead(SW_B)){
        buttonHintsVisible = true;
        lv_obj_clear_flag(ejectButton, LV_OBJ_FLAG_HIDDEN);
        lv_obj_clear_flag(ejectHint, LV_OBJ_FLAG_HIDDEN);
        lv_obj_clear_flag(settingsButton, LV_OBJ_FLAG_HIDDEN);
        lv_obj_clear_flag(settingsHint, LV_OBJ_FLAG_HIDDEN);
        lv_timer_ready(hintTimer);
        lv_timer_reset(hintTimer);
        delay(100);
      }
    }
  }

  /*Save the pressed key and set the state*/
  if(key != 0) {
      data->state = LV_INDEV_STATE_PR;
      last_key = key;
  } else {
      data->state = LV_INDEV_STATE_REL;
  }

  /*Set the last pressed key*/  
  data->key = last_key;
}

static void return_button_event_cb(lv_event_t * e)
{
    lv_event_code_t code = lv_event_get_code(e);
    if(code == LV_EVENT_CLICKED) {
        // Switch to the first tab (index 0) without animation
        lv_tabview_set_act(tabview, 0, LV_ANIM_OFF);
    }
}

static void day_button_event_cb(lv_event_t * e)
{
    if(lv_event_get_code(e) == LV_EVENT_CLICKED) {
        t.day = (t.day % 31) + 1; // Cycle through days 1-31
        rtc_set_datetime(&t);
        lv_label_set_text_fmt(dayButtonL, "%02d.", t.day);
    }
}

static void month_button_event_cb(lv_event_t * e)
{
    if(lv_event_get_code(e) == LV_EVENT_CLICKED) {
        t.month = (t.month % 12) + 1; // Cycle through months 1-12
        rtc_set_datetime(&t);
        lv_label_set_text_fmt(monthButtonL, "%02d.", t.month);
    }
}

static void year_button_event_cb(lv_event_t * e)
{
    if(lv_event_get_code(e) == LV_EVENT_CLICKED) {
        t.year = (t.year < 2034) ? t.year + 1 : 2024; // Cycle through years 2024-2034
        rtc_set_datetime(&t);
        lv_obj_t * btn = lv_event_get_target(e);
        lv_obj_t * label = lv_obj_get_child(btn, 0);
        lv_label_set_text_fmt(label, "%04d", t.year);
    }
}

static void weekday_button_event_cb(lv_event_t * e)
{
    if(lv_event_get_code(e) == LV_EVENT_CLICKED) {
        t.dotw = (t.dotw + 1) % 7;
        rtc_set_datetime(&t);
        Serial.println(t.dotw);
        lv_obj_t * btn = lv_event_get_target(e);
        lv_obj_t * label = lv_obj_get_child(btn, 0);
        lv_label_set_text(label, weekdays_GERMAN[t.dotw]);
    }
}

static void hour_button_event_cb(lv_event_t * e)
{
    if(lv_event_get_code(e) == LV_EVENT_CLICKED) {
        t.hour = (t.hour + 1) % 24; // Cycle through hours 0-23
        rtc_set_datetime(&t);
        lv_label_set_text_fmt(hourButtonL, "%02d:", t.hour);
    }
}

static void minute_button_event_cb(lv_event_t * e)
{
    if(lv_event_get_code(e) == LV_EVENT_CLICKED) {
        t.min = (t.min + 1) % 60; // Cycle through minutes 0-59
        rtc_set_datetime(&t);
        lv_label_set_text_fmt(minuteButtonL, "%02d", t.min);
    }
}

float getVBat(){
  float sum = 0;
  for (int i = 0; i < 16; i++) {
    sum += 0.001 * 2 * (0.806 * analogRead(A1) - 0.806 * analogRead(A0));
  }
  return sum / 16;   
}

// Set the H-bridge state
void h_bridge_set(int hbrState){
  switch (hbrState){
    case A_POS: // Terminal A positive and Terminal B negative
      digitalWrite(HBR_AL, LOW);
      digitalWrite(HBR_AH, HIGH);
      digitalWrite(HBR_BL, HIGH);
      digitalWrite(HBR_BH, LOW);
      break;
    case B_POS: // Terminal B positive and Terminal A negative
      digitalWrite(HBR_AL, HIGH);
      digitalWrite(HBR_AH, LOW);
      digitalWrite(HBR_BL, LOW);
      digitalWrite(HBR_BH, HIGH);
      break;
    case OFF: // All MOSFETs off
    default:
      digitalWrite(HBR_AL, LOW);
      digitalWrite(HBR_AH, LOW);
      digitalWrite(HBR_BL, LOW);
      digitalWrite(HBR_BH, LOW);
  }  
}

// Source: http://www.scynd.de/tutorials/arduino-tutorials/5-sensoren/5-1-temperatur-mit-10k%CF%89-ntc.html
float NTCTemp(pin_size_t ADC_pin, int n_measurements){

  const int ntcNominal = 10000;         // Wiederstand des NTC bei Nominaltemperatur
  const int tempNominal = 25;           // Temperatur bei der der NTC den angegebenen Wiederstand hat
  const int bCoefficient = 3380;        // Beta Coefficient(B25 aus Datenblatt des NTC)

  int series_resistor = 10000;

  int measurements = 0;
  for (int i=0; i < n_measurements; i++)
  {
    measurements += analogRead(ADC_pin);
    delay(10);
  }   
  float average = measurements /= n_measurements;
   
  // Convert the ADC value to a resistance
  average = 4096 / average - 1;
  average = series_resistor / average;
   
  // Umrechnung aller Ergebnisse in die Temperatur mittels einer Steinhard Berechnung
  float temp = average / ntcNominal;     // (R/Ro)
  temp = log(temp);                     // ln(R/Ro)
  temp /= bCoefficient;                 // 1/B * ln(R/Ro)
  temp += 1.0 / (tempNominal + 273.15); // + (1/To)
  temp = 1.0 / temp;                    // Invertieren
  temp -= 273.15;                       // Umwandeln in °C

  return temp;
}

void fsm_idle(){ 
  // keep the servo in the lowest position
  while(currentServoPos != LowerServoLimit){      
    if(currentServoPos < LowerServoLimit) servo.writeMicroseconds(currentServoPos++);
    if(currentServoPos > LowerServoLimit) servo.writeMicroseconds(currentServoPos--);
    delay(3);
  } 
  // Check if a battery is in the feeder chute
  if(vcnl4040.getProximity() > proxThreshold ){
    //battery detected!
    fsm_currentState = FEED;    
  }
}

void fsm_feed(){
  // move the feeder arm up
  while(currentServoPos < UpperServoLimit){      
    servo.writeMicroseconds(currentServoPos++);
    delay(3);
  }
  // Show statis
  lv_label_set_text_fmt(infoLabel, "Loading Cell...");
  lv_timer_handler();
  // wait for the battery to drop into the feeder arm 
  delay(1000);
  fsm_currentState = CONTACT;
}

void fsm_contact(){
  hbrdge_currentState = OFF;
  h_bridge_set(hbrdge_currentState);

  // move the feeder arm to to the middle
  while(currentServoPos > ServoContactPos){      
    servo.writeMicroseconds(currentServoPos--);
    delay(10);
  }
  delay(500);
  // sanity check - proper battery voltage?
  if(abs(getVBat()) < 0.2 || abs(getVBat()) > 1.40){
    fsm_currentState = ENDCHARGE;
  }
  // find out the polarity and set the h-bridge accordingly
  else{
    if(getVBat() >= 0){
      hbrdge_currentState = A_POS;
    }
    else{
      hbrdge_currentState = B_POS;
    }    
    h_bridge_set(hbrdge_currentState);
    // turn off servo while charging
    servo.detach();
    // wait a moment for the charge IC to check the battery
    lv_label_set_text_fmt(infoLabel, "Checking Cell...");
    lv_timer_handler();
    for(int i = 0; i < 3000; i+=100){
      
      delay(100);
    }    
    fsm_currentState = CHARGE;
  }
}

void fsm_charge(){
  boolean chargingOK = true;

  // check if temperature is within limits
  float currentTemperature = NTCTemp(ADC_TEMP_BAT, 5);
  if(currentTemperature > 60 || currentTemperature < 0){
    chargingOK = false;
  }

  // update status label
  switch((millis() / 500) % 4){
    case 0: 
      //lv_label_set_text_fmt(infoLabel, LV_SYMBOL_BATTERY_1);
      lv_label_set_text_fmt(infoLabel, "%.2fV  %s", abs(getVBat()), LV_SYMBOL_BATTERY_1);
      break;
    case 1: 
      lv_label_set_text_fmt(infoLabel, "%.2fV  %s", abs(getVBat()), LV_SYMBOL_BATTERY_2);
      break;
    case 2: 
      lv_label_set_text_fmt(infoLabel, "%.2fV  %s", abs(getVBat()), LV_SYMBOL_BATTERY_3);
      break;
    case 3: 
      lv_label_set_text_fmt(infoLabel, "%.2fV  %s", abs(getVBat()), LV_SYMBOL_BATTERY_FULL);
      break;
  }
  
  // Detect end of charge or fault condition
  if(digitalRead(CHG_STAT) == HIGH){
    // clear info label
    lv_label_set_text_fmt(infoLabel, "");
    fsm_currentState = ENDCHARGE;
  }  
}

void fsm_endcharge(){
  // update info label
  lv_label_set_text_fmt(infoLabel, "Ejecting Cell...");
  lv_timer_handler();
  servo.attach(PWM_SERVO);

  hbrdge_currentState = OFF;
  h_bridge_set(hbrdge_currentState);

  // keep the servo in the lowest position
  while(currentServoPos != LowerServoLimit){      
    if(currentServoPos < LowerServoLimit) servo.writeMicroseconds(currentServoPos++);
    if(currentServoPos > LowerServoLimit) servo.writeMicroseconds(currentServoPos--);
    delay(3);
  }
  delay(1000);

  fsm_currentState = IDLE;

  lv_label_set_text_fmt(infoLabel, "");
  lv_timer_handler();
}
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
void loop() {
  // Blink debug LED at 1 Hz
  digitalWrite(USER_LED, millis() % 1000 > 500);
  
  #ifdef DEBUGDISPLAY 
  
    display.setTextColor(BLACK);
    display.setTextSize(2);
    display.setCursor(0, 10);  

    display.fillScreen(WHITE);

    display.print("H-Bridge Satus: ");
    if(hbrdge_currentState == OFF) display.println("OFF");
    if(hbrdge_currentState == A_POS) display.println("A+ B-");
    if(hbrdge_currentState == B_POS) display.println("A- B+");  

    display.print("ADC_TEMP_BAT: ");
    display.print(NTCTemp(ADC_TEMP_BAT, 5));
    display.println("C");

    display.print("V_BAT: ");
    display.print(getVBat());
    display.println("V");

    display.print("Buttons pressed:");
    if(button_L.isPressed()) display.print("L ");
    if(button_R.isPressed()) display.print("R");
    display.println();

    display.print("Charge status: ");
    if(digitalRead(CHG_STAT)) display.println("complete/disabled");
    else display.println("charging");

    display.print("Proximity: ");
    display.print("-");
    display.print(vcnl4040.getProximity());
    display.println();

    display.print("Servo Position: ");
    display.print(currentServoPos);
    display.println();

    display.print("State Machine is at: ");
    display.print(fsm_currentState);
    display.println();

  #endif
  
  // Update servo position
  currentServoPos = constrain(currentServoPos, LowerServoLimit, UpperServoLimit);
  servo.writeMicroseconds(currentServoPos);
  
  // Handle the state machine
  switch(fsm_currentState){
  case IDLE:
    fsm_idle();
    break;
  case FEED:
    fsm_feed();
    break;
  case CONTACT:
    fsm_contact();
    break;
  case CHARGE:
    fsm_charge();
    break;
  case ENDCHARGE:
    fsm_endcharge();
    break;
  }

  // Update the clock display
  rtc_get_datetime(&t);
  if(tOld.min != t.min || tOld.hour != t.hour){ // avoid updating the time label too often (increases FPS)
    lv_label_set_text_fmt(timeLabel, "%d:%02d", t.hour, t.min);
  }
  if(tOld.day != t.day || tOld.month != t.month || tOld.dotw != t.dotw){ // avoid updating the date label too often (increases FPS)
    lv_label_set_text_fmt(dateLabel, "%s, %d. %s", weekdays_GERMAN[t.dotw], t.day, months_GERMAN[t.month]);
  }
  tOld = t;

  
  // Update LVGL UI
  lv_timer_handler();
}

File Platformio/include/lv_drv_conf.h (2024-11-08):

/**
 * @file lv_drv_conf.h
 * Configuration file for v8.3.0
 */

/*
 * COPY THIS FILE AS lv_drv_conf.h
 */

/* clang-format off */
#if 1 /*Set it to "1" to enable the content*/

#ifndef LV_DRV_CONF_H
#define LV_DRV_CONF_H

#include "lv_conf.h"

/*********************
 * DELAY INTERFACE
 *********************/
#define LV_DRV_DELAY_INCLUDE  <stdint.h>            /*Dummy include by default*/
#define LV_DRV_DELAY_US(us)  /*delay_us(us)*/       /*Delay the given number of microseconds*/
#define LV_DRV_DELAY_MS(ms)  /*delay_ms(ms)*/       /*Delay the given number of milliseconds*/

/*********************
 * DISPLAY INTERFACE
 *********************/

/*------------
 *  Common
 *------------*/
#define LV_DRV_DISP_INCLUDE         <stdint.h>           /*Dummy include by default*/
#define LV_DRV_DISP_CMD_DATA(val)  /*pin_x_set(val)*/    /*Set the command/data pin to 'val'*/
#define LV_DRV_DISP_RST(val)       /*pin_x_set(val)*/    /*Set the reset pin to 'val'*/

/*---------
 *  SPI
 *---------*/
#define LV_DRV_DISP_SPI_CS(val)          spi_cs_set(val)     /*Set the SPI's Chip select to 'val'*/
#define LV_DRV_DISP_SPI_WR_BYTE(data)    spi_wr(data)        /*Write a byte the SPI bus*/
#define LV_DRV_DISP_SPI_WR_ARRAY(adr, n) spi_wr_mem(adr, n)  /*Write 'n' bytes to SPI bus from 'adr'*/

/*------------------
 *  Parallel port
 *-----------------*/
#define LV_DRV_DISP_PAR_CS(val)          /*par_cs_set(val)*/   /*Set the Parallel port's Chip select to 'val'*/
#define LV_DRV_DISP_PAR_SLOW             /*par_slow()*/        /*Set low speed on the parallel port*/
#define LV_DRV_DISP_PAR_FAST             /*par_fast()*/        /*Set high speed on the parallel port*/
#define LV_DRV_DISP_PAR_WR_WORD(data)    /*par_wr(data)*/      /*Write a word to the parallel port*/
#define LV_DRV_DISP_PAR_WR_ARRAY(adr, n) /*par_wr_mem(adr,n)*/ /*Write 'n' bytes to Parallel ports from 'adr'*/

/***************************
 * INPUT DEVICE INTERFACE
 ***************************/

/*----------
 *  Common
 *----------*/
#define LV_DRV_INDEV_INCLUDE     <stdint.h>             /*Dummy include by default*/
#define LV_DRV_INDEV_RST(val)    /*pin_x_set(val)*/     /*Set the reset pin to 'val'*/
#define LV_DRV_INDEV_IRQ_READ    0 /*pn_x_read()*/      /*Read the IRQ pin*/

/*---------
 *  SPI
 *---------*/
#define LV_DRV_INDEV_SPI_CS(val)            /*spi_cs_set(val)*/     /*Set the SPI's Chip select to 'val'*/
#define LV_DRV_INDEV_SPI_XCHG_BYTE(data)    0 /*spi_xchg(val)*/     /*Write 'val' to SPI and give the read value*/

/*---------
 *  I2C
 *---------*/
#define LV_DRV_INDEV_I2C_START              /*i2c_start()*/       /*Make an I2C start*/
#define LV_DRV_INDEV_I2C_STOP               /*i2c_stop()*/        /*Make an I2C stop*/
#define LV_DRV_INDEV_I2C_RESTART            /*i2c_restart()*/     /*Make an I2C restart*/
#define LV_DRV_INDEV_I2C_WR(data)           /*i2c_wr(data)*/      /*Write a byte to the I1C bus*/
#define LV_DRV_INDEV_I2C_READ(last_read)    0 /*i2c_rd()*/        /*Read a byte from the I2C bud*/


/*********************
 *  DISPLAY DRIVERS
 *********************/

/*-------------------
 *  SDL
 *-------------------*/

/* SDL based drivers for display, mouse, mousewheel and keyboard*/
#ifndef USE_SDL
# define USE_SDL 0
#endif

/* Hardware accelerated SDL driver */
#ifndef USE_SDL_GPU
# define USE_SDL_GPU 0
#endif

#if USE_SDL || USE_SDL_GPU
#  define SDL_HOR_RES     480
#  define SDL_VER_RES     320

/* Scale window by this factor (useful when simulating small screens) */
#  define SDL_ZOOM        1

/* Used to test true double buffering with only address changing.
 * Use 2 draw buffers, bith with SDL_HOR_RES x SDL_VER_RES size*/
#  define SDL_DOUBLE_BUFFERED 0

/*Eclipse: <SDL2/SDL.h>    Visual Studio: <SDL.h>*/
#  define SDL_INCLUDE_PATH    <SDL2/SDL.h>

/*Open two windows to test multi display support*/
#  define SDL_DUAL_DISPLAY            0
#endif

/*-------------------
 *  Monitor of PC
 *-------------------*/

/*DEPRECATED: Use the SDL driver instead. */
#ifndef USE_MONITOR
#  define USE_MONITOR         0
#endif

#if USE_MONITOR
#  define MONITOR_HOR_RES     480
#  define MONITOR_VER_RES     320

/* Scale window by this factor (useful when simulating small screens) */
#  define MONITOR_ZOOM        1

/* Used to test true double buffering with only address changing.
 * Use 2 draw buffers, bith with MONITOR_HOR_RES x MONITOR_VER_RES size*/
#  define MONITOR_DOUBLE_BUFFERED 0

/*Eclipse: <SDL2/SDL.h>    Visual Studio: <SDL.h>*/
#  define MONITOR_SDL_INCLUDE_PATH    <SDL2/SDL.h>

/*Open two windows to test multi display support*/
#  define MONITOR_DUAL            0
#endif

/*-----------------------------------
 *  Native Windows (including mouse)
 *----------------------------------*/
#ifndef USE_WINDOWS
#  define USE_WINDOWS       0
#endif

#if USE_WINDOWS
#  define WINDOW_HOR_RES      480
#  define WINDOW_VER_RES      320
#endif

/*----------------------------
 *  Native Windows (win32drv)
 *---------------------------*/
#ifndef USE_WIN32DRV
#  define USE_WIN32DRV       0
#endif

#if USE_WIN32DRV
/* Scale window by this factor (useful when simulating small screens) */
#  define WIN32DRV_MONITOR_ZOOM        1
#endif

/*----------------------------------------
 *  GTK drivers (monitor, mouse, keyboard
 *---------------------------------------*/
#ifndef USE_GTK
#  define USE_GTK       0
#endif

/*----------------------------------------
 *  Wayland drivers (monitor, mouse, keyboard, touchscreen)
 *---------------------------------------*/
#ifndef USE_WAYLAND
#  define USE_WAYLAND       0
#endif

#if USE_WAYLAND
/* Support for client-side decorations */
#  ifndef LV_WAYLAND_CLIENT_SIDE_DECORATIONS
#    define LV_WAYLAND_CLIENT_SIDE_DECORATIONS 1
#  endif
/* Support for (deprecated) wl-shell protocol */
#  ifndef LV_WAYLAND_WL_SHELL
#    define LV_WAYLAND_WL_SHELL 1
#  endif
/* Support for xdg-shell protocol */
#  ifndef LV_WAYLAND_XDG_SHELL
#    define LV_WAYLAND_XDG_SHELL 0
#  endif
#endif

/*----------------
 *    SSD1963
 *--------------*/
#ifndef USE_SSD1963
#  define USE_SSD1963         0
#endif

#if USE_SSD1963
#  define SSD1963_HOR_RES     LV_HOR_RES
#  define SSD1963_VER_RES     LV_VER_RES
#  define SSD1963_HT          531
#  define SSD1963_HPS         43
#  define SSD1963_LPS         8
#  define SSD1963_HPW         10
#  define SSD1963_VT          288
#  define SSD1963_VPS         12
#  define SSD1963_FPS         4
#  define SSD1963_VPW         10
#  define SSD1963_HS_NEG      0   /*Negative hsync*/
#  define SSD1963_VS_NEG      0   /*Negative vsync*/
#  define SSD1963_ORI         0   /*0, 90, 180, 270*/
#  define SSD1963_COLOR_DEPTH 16
#endif

/*----------------
 *    R61581
 *--------------*/
#ifndef USE_R61581
#  define USE_R61581          0
#endif
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

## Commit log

2024-11-08 Initial Upload
    [280QV10 v5.step, 541325062_colored.step, 68711014022 (rev1).stp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]
2024-11-22 Small fixes for the PCB
    - Changed fuse from 500mA to 1A (when charging at full 1A, the device draws slightly more than 500mA)
    - Changed R32 from 80k to 22k (somehow the cell check fails with 100mV sensitivity)
    [SPINC AA Charger.kicad_pcb, SPINC AA Charger.kicad_sch]
2024-12-03 Added fabrication files
    - Please double-check the files before odering anything!
    - The BOM does not include JLCPCB numbers yet.
    [bom.csv, designators.csv, positions.csv]
2025-01-12 Modified arm to give room for the ESP32.
    [Arm.stl]
2025-01-12 Updated servo hole size to be able to fit a SG90.
    [Shell L.stl]
